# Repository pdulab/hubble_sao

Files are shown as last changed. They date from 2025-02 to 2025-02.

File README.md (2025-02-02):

## Features

The main features of the SAO are :
- An optical sensor : a VEML3328 to provide a 1x1 pixel RGB+IR camera
- An IMU (accel + gyro) : an LSM6DSO, because every good telescope needs to know its orientation (note that only one remaining gyroscope is working correctly on Hubble, so my SAO has the same number of gyroscope, nice !)
- 4 photodiodes : they represent the solar panels of Hubble. I'm using BPW34s (the IR version, to be precise). They are wired to the ADC of the microcontroller.
- An IR LED : to provide a way to send wireless data
- An microcontroller : I used a ATmega328PB

On top of that, there are :

- A standard yellow LED, because an SAO would be nothing without some blinky LEDs
- A button

## License
 Hubble SAO by pdulab is licensed under CC BY-NC-SA 4.0 

 ## Disclaimer
 This is a project for fun. I do not guarantee anything about it.
 The author is not affiliated with the official Hubble Space Telescope project or endorsed by it (or any related organization) in any way whatsoever.

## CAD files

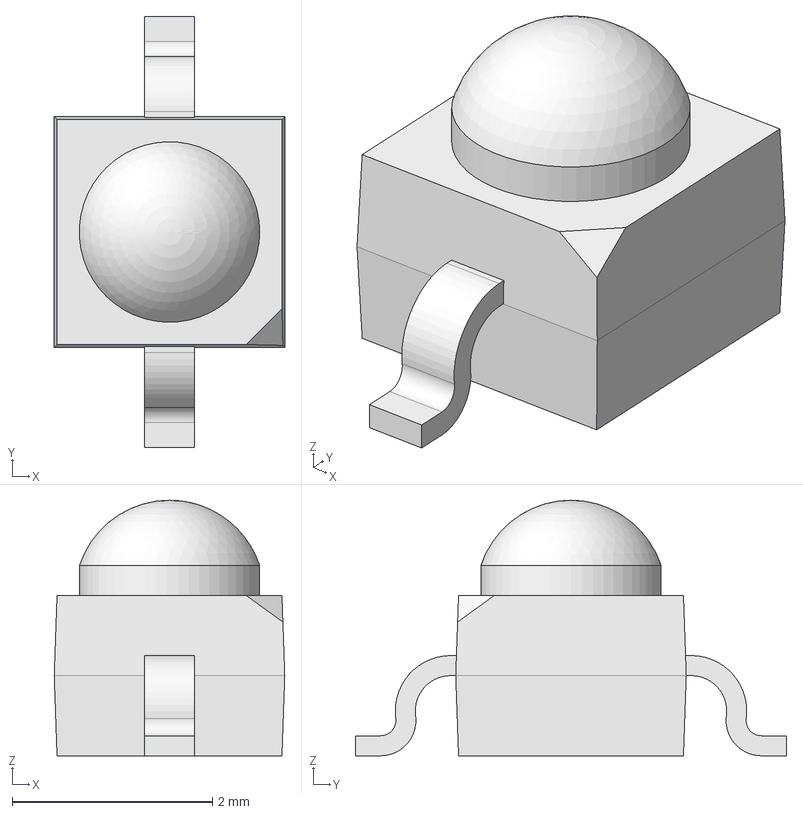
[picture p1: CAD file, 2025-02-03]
3d_models/VxMx.FCStd
2.30 x 4.30 x 2.55 mm

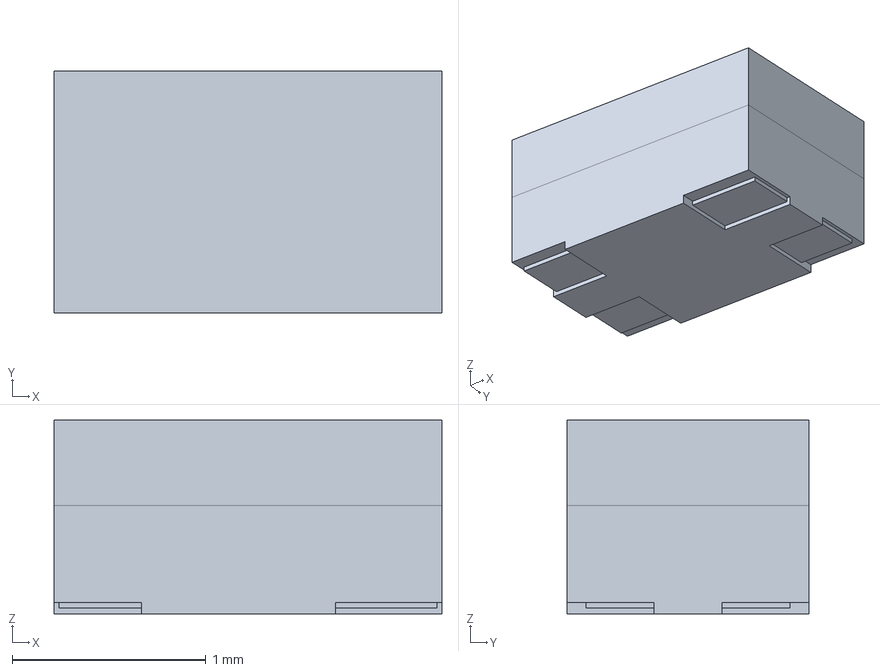
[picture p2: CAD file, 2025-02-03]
3d_models/VEML3328.FCStd
2.00 x 1.25 x 1.00 mm

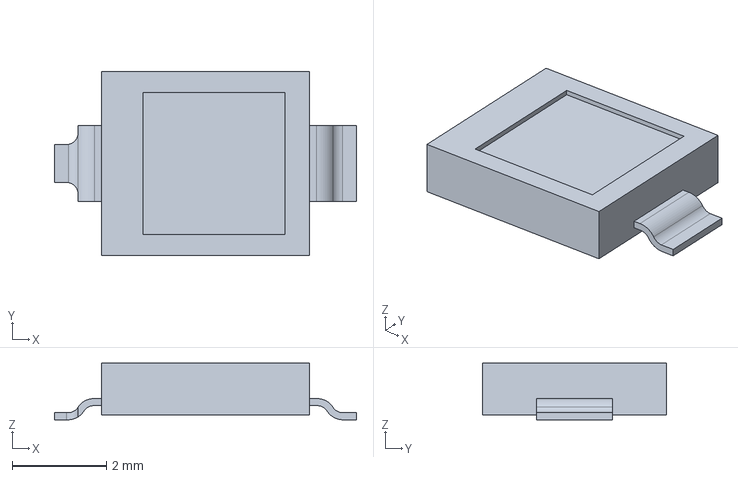
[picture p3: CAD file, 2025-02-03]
3d_models/VBPW34FAS.FCStd
6.40 x 3.90 x 1.20 mm

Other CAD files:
3d_models/VBPW34.step
3d_models/VxMx_LED.step
3d_models/VEML3328.stl

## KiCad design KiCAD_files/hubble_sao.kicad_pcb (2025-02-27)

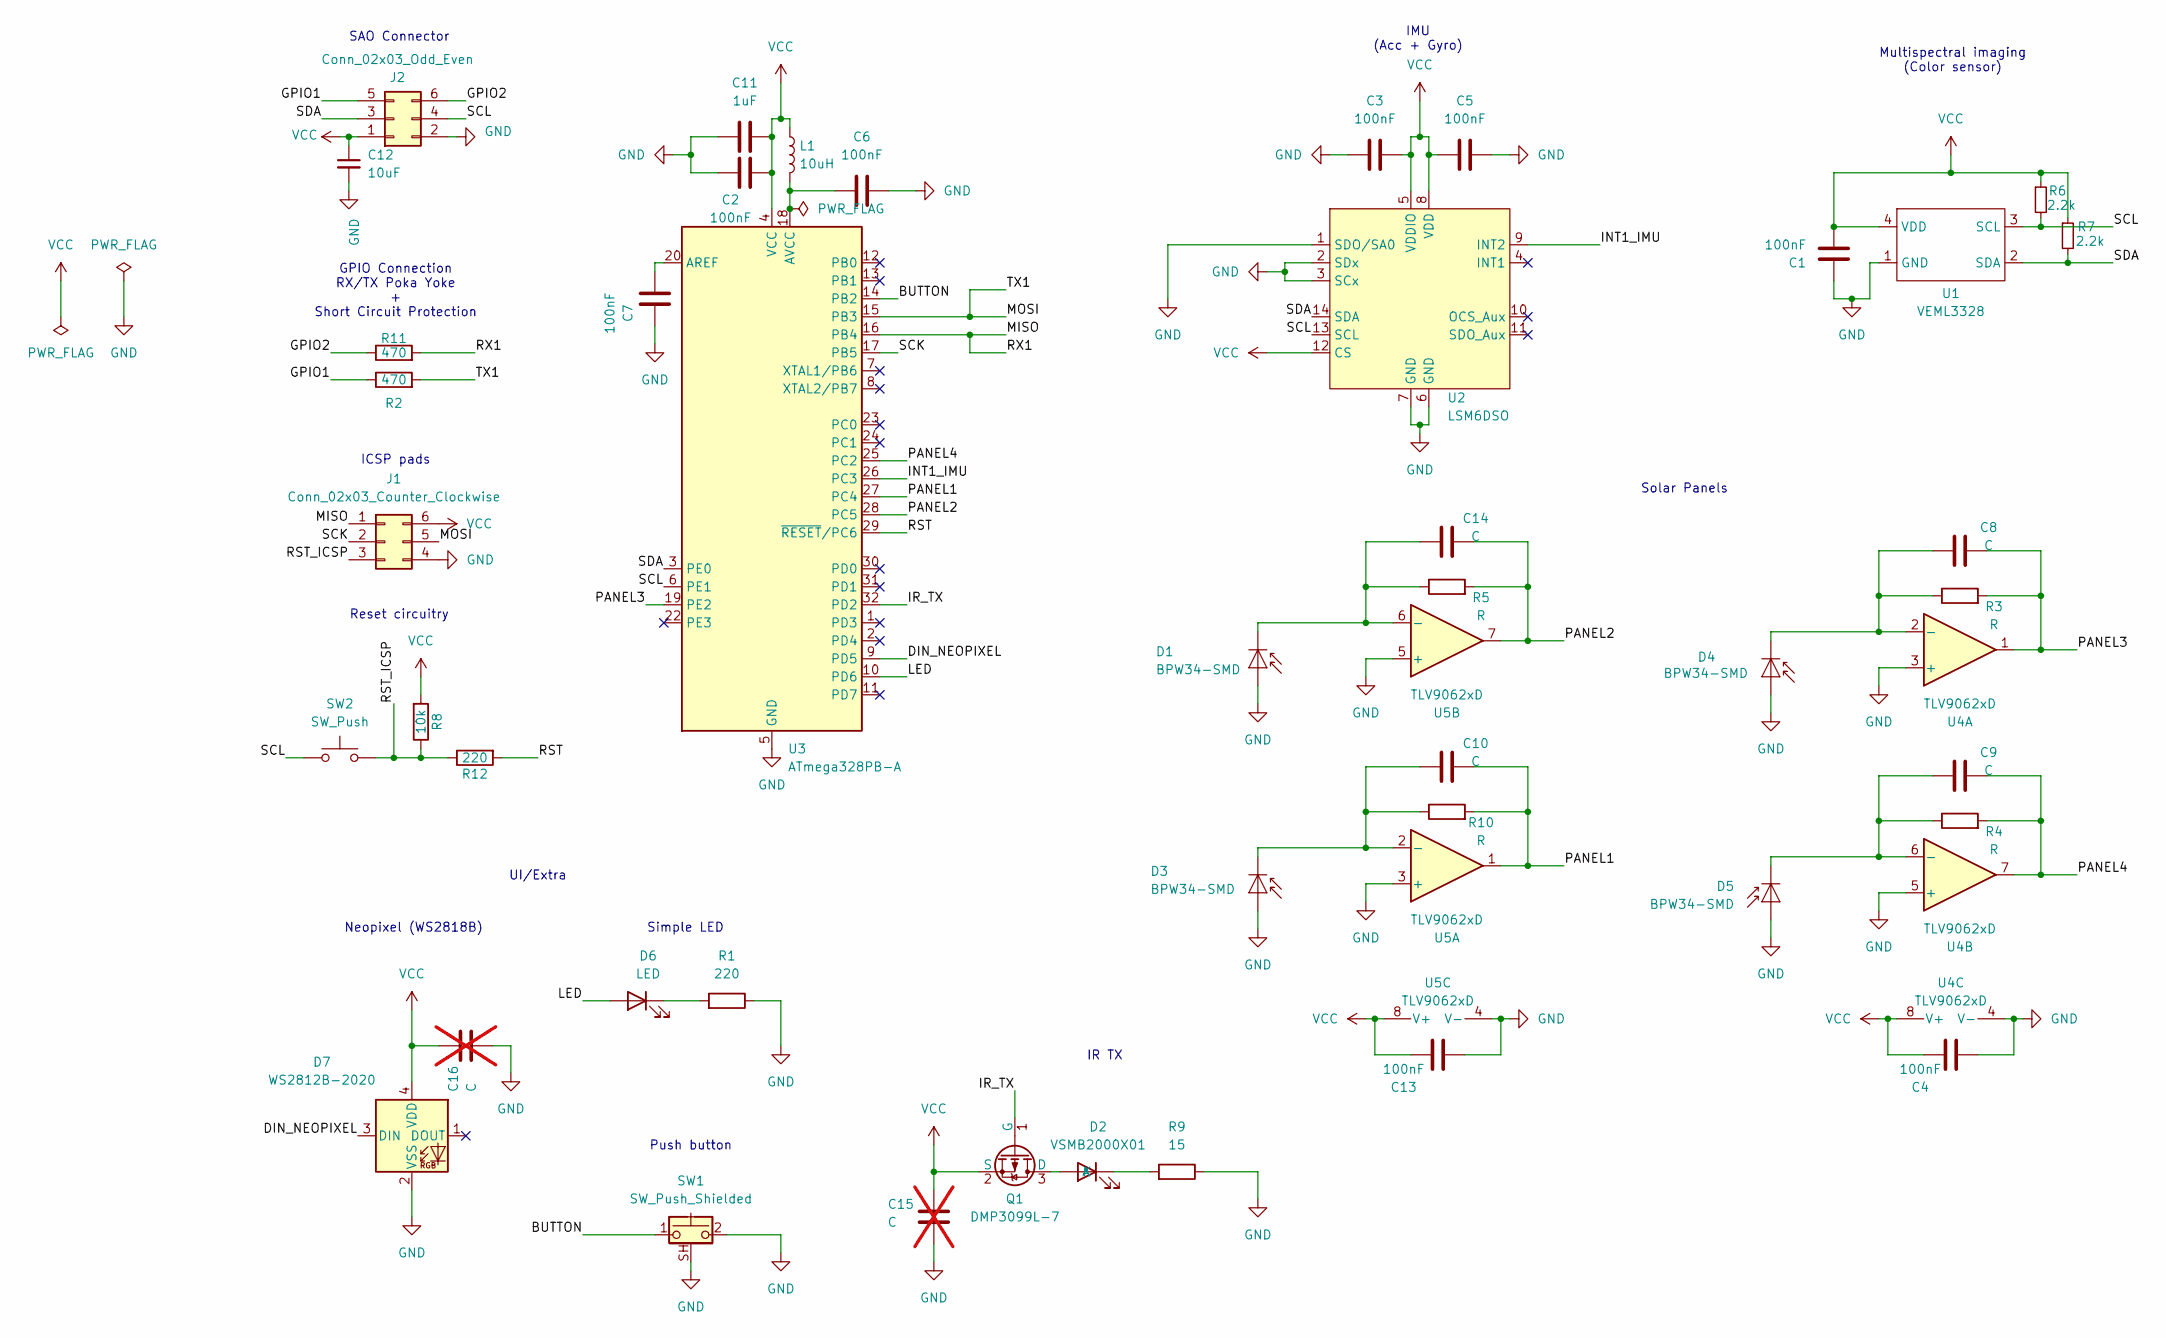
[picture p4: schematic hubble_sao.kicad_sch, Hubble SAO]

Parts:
C1, C2, C3, C4, C5, C6, C7, C13: 100nF; C_0805_2012Metric_Pad1.18x1.45mm_HandSolder
C8, C9, C10, C14: C; C_0805_2012Metric_Pad1.18x1.45mm_HandSolder
C11: 1uF; C_0805_2012Metric_Pad1.18x1.45mm_HandSolder
C12: 10uF; C_1206_3216Metric_Pad1.33x1.80mm_HandSolder
C15, C16: C; C_0603_1608Metric_Pad1.08x0.95mm_HandSolder; not fitted
D1, D3, D4, D5: BPW34-SMD; Osram_BPW34S-SMD
D2: VSMB2000X01; VxMx2000X01
D6: LED; LED_LiteOn_LTST-S110
D7: WS2812B-2020; LED_WS2812B-2020_PLCC4_2.0x2.0mm
J1: Conn_02x03_Counter_Clockwise; Pogo_pads_2x3_P2.54mm
J2: Conn_02x03_Odd_Even; PinHeader_2x03_P2.54mm_Vertical
L1: 10uH; L_0805_2012Metric_Pad1.15x1.40mm_HandSolder
Q1: DMP3099L-7; SOT-23
R1, R12: 220; R_0805_2012Metric_Pad1.20x1.40mm_HandSolder
R2, R11: 470; R_0805_2012Metric_Pad1.20x1.40mm_HandSolder
R3, R4, R5, R10: R; R_0805_2012Metric_Pad1.20x1.40mm_HandSolder
R6, R7: 2.2k; R_0805_2012Metric_Pad1.20x1.40mm_HandSolder
R8: 10k; R_0805_2012Metric_Pad1.20x1.40mm_HandSolder
R9: 15; R_1206_3216Metric_Pad1.30x1.75mm_HandSolder
SW1: SW_Push_Shielded; SW_SPST_B3U-1100P
SW2: SW_Push; SW_SPST_B3U-1000P
U1: VEML3328
U2: LSM6DSO; LGA-14_3x2.5mm_P0.5mm_LayoutBorder3x4y
U3: ATmega328PB-A; TQFP-32_7x7mm_P0.8mm
U4, U5: TLV9062xD; SOIC-8_3.9x4.9mm_P1.27mm

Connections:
/BUTTON: SW1.1, U3.14 (PB2)
/DIN_NEOPIXEL: D7.3 (DIN), U3.9 (PD5)
/GPIO1: J2.5, R2.1
/GPIO2: J2.6, R11.1
/INT1_IMU: U2.9 (INT2), U3.26 (PC3)
/IR_TX: Q1.1 (G), U3.32 (PD2)
/LED: D6.2 (A), U3.10 (PD6)
/MISO: J1.1, R11.2, U3.16 (PB4)
/MOSI: J1.5, R2.2, U3.15 (PB3)
/PANEL1: C10.2, R10.2, U3.27 (PC4), U5.1
/PANEL2: C14.2, R5.2, U3.28 (PC5), U5.7
/PANEL3: C8.2, R3.2, U3.19 (PE2), U4.1
/PANEL4: C9.2, R4.2, U3.25 (PC2), U4.7
/RST: R12.2, U3.29 (~RESET/PC6)
/RST_ICSP: J1.3, R8.1, R12.1, SW2.2
/SCK: J1.2, U3.17 (PB5)
/SCL: J2.4, R6.2, SW2.1, U1.3 (SCL), U2.13 (SCL), U3.6 (PE1)
/SDA: J2.3, R7.2, U1.2 (SDA), U2.14 (SDA), U3.3 (PE0)
GND: C1.1, C2.1, C3.2, C4.1, C5.2, C6.2, C7.1, C11.1, C12.2, C13.1, C15.2, C16.2, D1.2 (A), D3.2 (A), D4.2 (A), D5.2 (A), D7.2 (VSS), J1.4, J2.2, R1.1, R9.1, SW1.2, SW1.SH (B), U1.1 (GND), U2.1 (SDO/SA0), U2.2 (SDx), U2.3 (SCx), U2.6 (GND), U2.7 (GND), U3.5 (GND), U3.21 (GND), U4.3 (+), U4.4 (V-), U4.5 (+), U5.3 (+), U5.4 (V-), U5.5 (+)
unnamed: C14.1, D1.1 (K), R5.1, U5.6 (-)
unnamed: D2.2 (A), Q1.3 (D)
unnamed: D2.1 (K), R9.2
unnamed: C10.1, D3.1 (K), R10.1, U5.2 (-)
unnamed: C8.1, D4.1 (K), R3.1, U4.2 (-)
unnamed: C9.1, D5.1 (K), R4.1, U4.6 (-)
unnamed: D6.1 (K), R1.2
unnamed: C7.2, U3.20 (AREF)
unnamed: C6.1, L1.2, U3.18 (AVCC)
VCC: C1.2, C2.2, C3.1, C4.2, C5.1, C11.2, C12.1, C13.2, C15.1, C16.1, D7.4 (VDD), J1.6, J2.1, L1.1, Q1.2 (S), R6.1, R7.1, R8.2, U1.4 (VDD), U2.5 (VDDIO), U2.8 (VDD), U2.12 (CS), U3.4 (VCC), U4.8 (V+), U5.8 (V+)

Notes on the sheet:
Solar Panels
UI/Extra
IMU (Acc + Gyro)
Multispectral imaging (Color sensor)
IR TX
SAO Connector
Push button
Simple LED
Neopixel (WS2818B)
Reset circuitry
GPIO Connection RX/TX Poka Yoke + Short Circuit Protection
ICSP pads

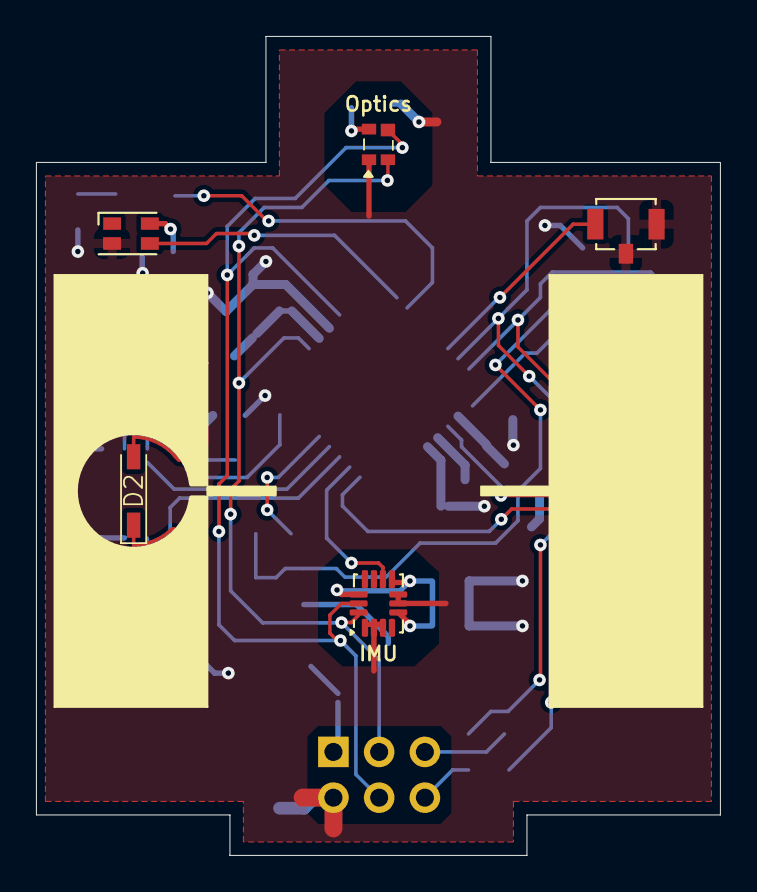
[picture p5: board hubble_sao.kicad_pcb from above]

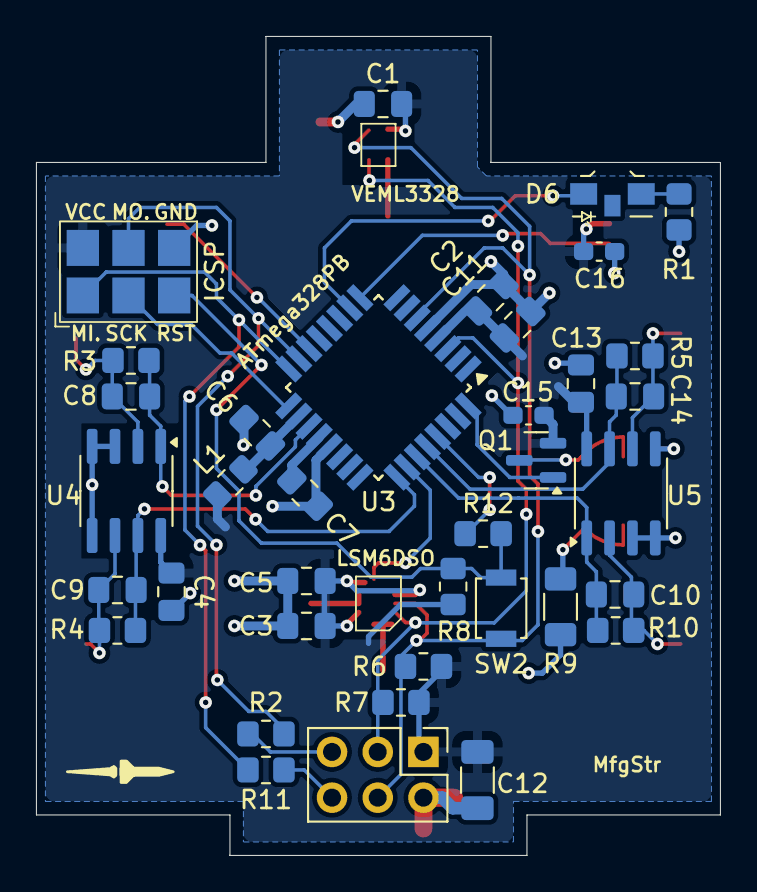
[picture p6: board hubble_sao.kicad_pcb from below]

Board: 2 copper layers, 38.0 x 45.5 mm, 46 parts (37 on the bottom side), 29 nets.

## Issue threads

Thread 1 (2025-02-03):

Reversed MOSFET

pdulab, 2025-02-03:
Drain and source are reversed on the pMOSFET that is used to drive the IR LED.

Closed 2025-02-05.

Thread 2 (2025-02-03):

Wrong footprint for the SAO connector

pdulab, 2025-02-03:
The SAO connector shoulded be a shrouded pin header. The footprint used here is the unshrouded version.

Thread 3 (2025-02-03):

Incorrect pins used to program the ATmega328PB

pdulab, 2025-02-03:
In the current state, the ATmega328PB cannot be programmed because the serial programming pins are not wired properly.
The ICSP header should use the following pins:

    MOSI -> PB5
    MISO -> PB6
    SCK -> PB7

Currently, the SAO uses pins :

    MOSI -> PB3
    MISO -> PB4
    SCK -> PB5

Reference : ATmega328PB datasheet, Fig. 32-6, page 400

pdulab, 2025-02-03:
After trying, and succeeding, at programming the ATmega328PB through serial programming, I can confirm that Fig. 32-6, page 400 is wrong.

The correct pin mapping for serial programming is given in Table 32-15 :

    MOSI -> PB3
    MISO -> PB4
    -SCK -> PB5
    This means that the wiring for serial programming as implemented on the SAO is, in fact, correct.

Previous failed attempts at programming were probably due to error from my part or an unreliable (or bad wiring) between the programmer and the SAO.

Additional notes :

    The datasheet with the incorrect pin mapping in Fig. 32-6 is "ATmega328PB - Complete Datasheet" Rev D. (?) (ref. DS40001906C)
    In the latest datasheet for the ATmega328P (ref. 7810D-AVR-01/15), the schematic for serial programming Fig. 27-7 does not indicate any pins. The pin mapping is only given in Table 27-15 and is the same as the one from Table 32-15 from the *PB datasheet.

I will try to notify the manufacturer of the incorrect pin mapping in Fig. 32-6.

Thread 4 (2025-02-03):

Add series resistors on GPIO1 and GPIO2 for short-circuit protection

pdulab, 2025-02-03:
Currently the GPIO1 and GPIO2 do not have series resistor. In case of an incorrect wiring or configuration, this can lead to a short-circuit, as the last test and a fried micro-controller seem to show.

Adding series resistors would limit the current in case of a problem. The resistors values should be chosen such that the max current is below 40mA (absolute maximum rating of IO pins, cf. ATmega328PB datasheet).

Closed 2025-02-22.

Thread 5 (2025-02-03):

OpAmps are inverted on the schematic

pdulab, 2025-02-03:
The inverting and non-inverting inputs of the op-amps should be the other way around.

This error probably appeared when copying the design from the reference design from Analog's Photodiode Circuit Design tool.

pdulab, 2025-02-03:
Fixed by 7deba7c84896e96d878b327c0d323b6033fc573d

Closed 2025-02-03.

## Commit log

2025-02-03 Adding project files
    [VBPW34.step, VBPW34FAS.FCStd, VEML3328.FCStd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]
2025-02-03 Corrected the input wiring of the opamps (schematic & pcb)
    [hubble_sao.kicad_pcb, hubble_sao.kicad_sch]
2025-02-03 Changed opamp from AD8532 to TLV9062D
    [hubble_sao.kicad_pcb, hubble_sao.kicad_sch]
2025-02-05 FIX: Corrected the pMOSFET wiring. Fixes #1
    [hubble_sao.kicad_pcb, hubble_sao.kicad_sch]
2025-02-05 Simplified the blinky LED's traces
    [hubble_sao.kicad_pcb, hubble_sao.kicad_sch]
2025-02-05 Fixed DRC errors
    [hubble_sao.kicad_pcb]
2025-02-08 Merged the front copper pours in a single ground plane
    [hubble_sao.kicad_pcb]
2025-02-08 Replaced some 1206 resistors by 0805s to tighten up the PCB
    [hubble_sao.kicad_pcb, hubble_sao.kicad_sch]
2025-02-08 Cleaned up the PCB around the IMU
    [hubble_sao.kicad_pcb]
2025-02-08 Renamed netclass VCC to Power. Included GND tracks to the new net class
    [hubble_sao.kicad_pcb]
2025-02-09 Replaced back GND plane/pour by a Power (VCC) plane/pour. Rerouted traces accordingly
    [hubble_sao.kicad_pcb]
2025-02-09 Cleaned up some traces
    [hubble_sao.kicad_pcb]
2025-02-22 Changed RX/TX resistors to 470Ohm for short circuit protection
    Fixes #4
    [hubble_sao.kicad_pcb, hubble_sao.kicad_sch]
2025-02-22 Created keep out around pin header
    - To enhance hand soldering (hopefully)
    - To still have soldermask instead of bare FR4 (was not the case before)
    [hubble_sao.kicad_pcb]
2025-02-24 Moved ICSP pads for an easier pogo pins positionning
    The ICSP pads are now positionned to be approx 0.1" and 0.2" from
    the board's sides. This means that alignement pins on a 0.1" grid
    can be used on the pogrammer's side to accurately position the
    pogo pins while programming. See User1 Layer for more info.
    [hubble_sao.kicad_pcb]
2025-02-24 Changed the manufacturer string/id to a default one
    [hubble_sao.kicad_pcb]
2025-02-25 Modified RESET circuitry
    - Added a switch to multiplex RESET and SCL on the pin header
    - Added short-circuit protection on the RESET pin
    - Added missing pullup resistor on the RESET pin. Before, RESET
    was left floating. No problem was noticed on the prototype.
    [hubble_sao.kicad_pcb, hubble_sao.kicad_sch]
2025-02-26 Moved Panel3 to 19/PE2/ADC6/ICP3
    This should enable the use of the Input Capture Pin 3.
    [hubble_sao.kicad_pcb, hubble_sao.kicad_sch]
2025-02-26 Reworked IR_TX LED
    - Removed the copper pour keep out and round copper traces (they
    were supposed too look nice, but in fact were not really visible)
    - Simplified the routing of the power around the MOSFET
    [hubble_sao.kicad_pcb]
2025-02-26 Added decoupling cap for the IR_TX LED (DNP for now) and touched up some tracks around there
    [hubble_sao.kicad_pcb, hubble_sao.kicad_sch]
2025-02-27 Fixed the silkscreen
    [hubble_sao.kicad_pcb]
2025-02-27 Modified blinky LEDs
    - Changed reverse mount LED for a side view LED
    - Added a WS2812N (Neopixel)
    [hubble_sao.kicad_pcb, hubble_sao.kicad_sch]
2025-02-27 Fixed some silkscreen
    [hubble_sao.kicad_pcb]
2025-02-27 A little bit of cleanup and verifications
    [hubble_sao.kicad_pcb]
2025-02-27 Touched up the schematic
    [hubble_sao.kicad_pcb, hubble_sao.kicad_sch]
2025-02-27 Updated version number to 2.0 and metadata
    [hubble_sao.kicad_pcb, hubble_sao.kicad_sch]
